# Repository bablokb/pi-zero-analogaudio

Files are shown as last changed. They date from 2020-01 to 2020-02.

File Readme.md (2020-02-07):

Pi-Zero-Analogaudio
===================

The Pi-Zero is a stripped down board, there is no analog audio jack
like on the bigger Pis. But it is no problem to add it using a few
simple and cheap components.

The schematic

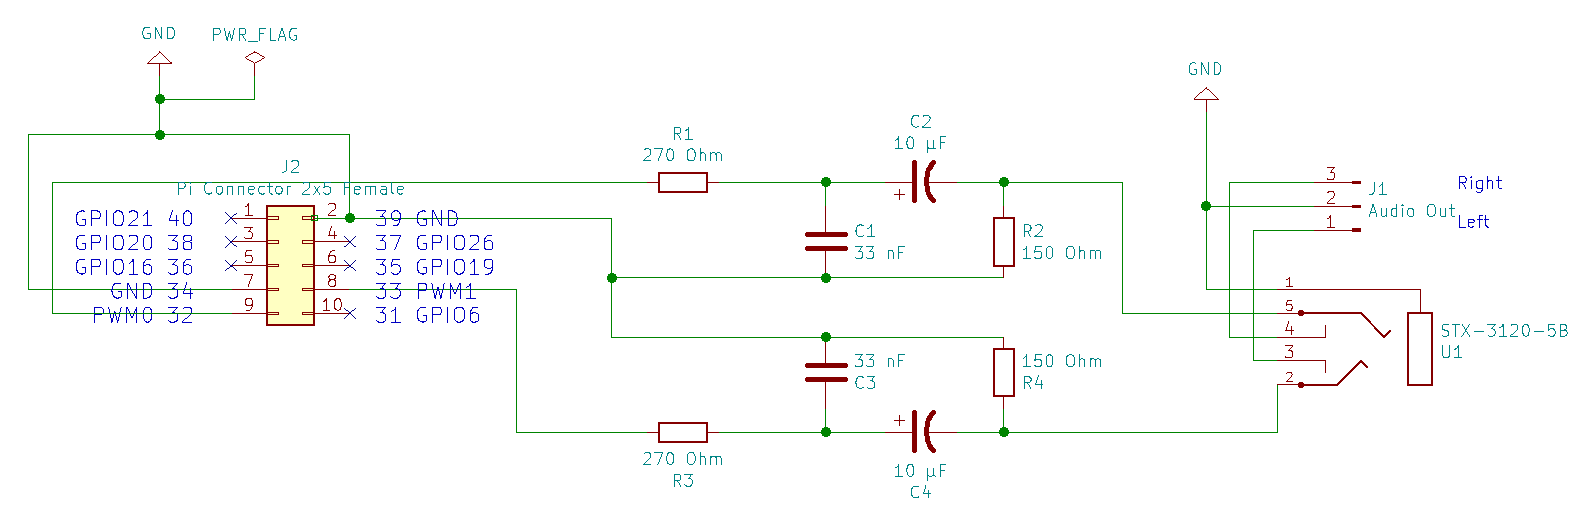
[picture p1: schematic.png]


shows the necessary parts and the wiring. Basically, you configure the
Zero to output pwm-signals, then you use a combination of a lowpass
and highpass filter to clean the signal on every channel.

The audio quality is ok, but not on hifi level. The filters limit the
frequency range and the signal is still not absolutely clean afterwards.
If you really need high-quality audio-output, use HDMI, bluetooth or
attach an audio-hat based on I2S using a DAC.

Hardware
========

Required parts:

  - two resistors 270 Ohm
  - two resistors 150 Ohm
  - two capacitors 33nF
  - two capacitors 10µF
  - an 3.5mm audio-jack (e.g. STX-3120-5B from Adafruit)
  - some jumper-wires

In the folder `kicad` you can find a complete pcb, designed for the above
throughhole components. You will need to adapt the design if you use a
different audio-jack.

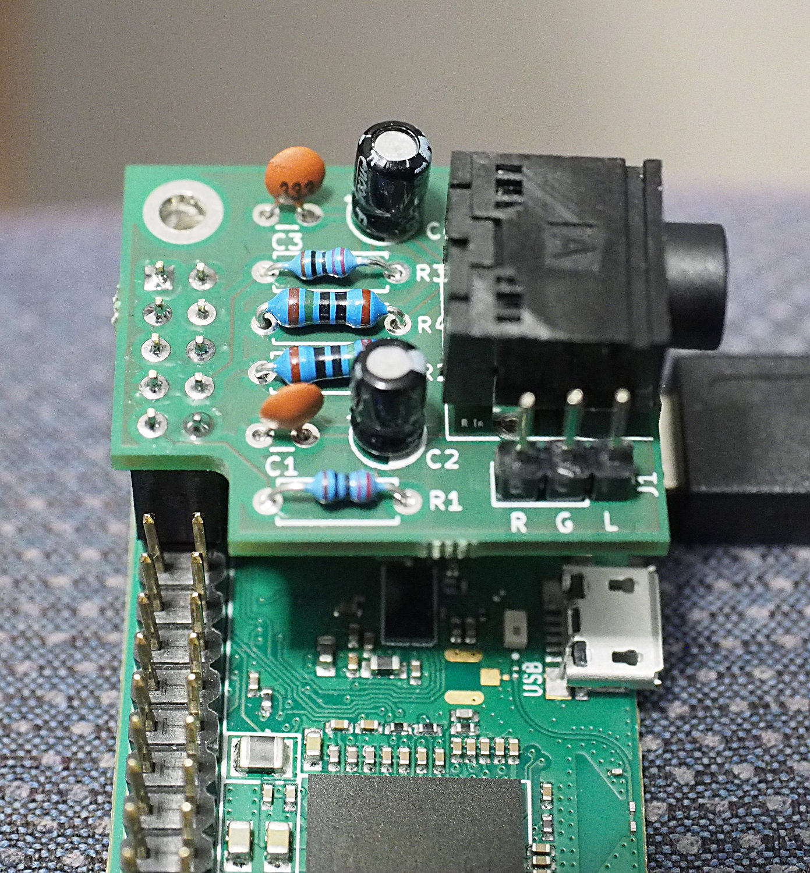
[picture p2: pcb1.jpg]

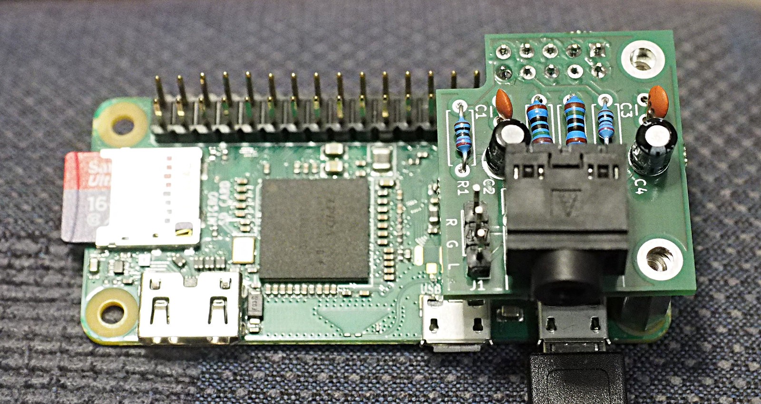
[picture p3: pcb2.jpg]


Software and System Configuration
=================================

You don't need special software, just use `aplay` to play wav-files or
e.g. `mpg123` for mp3-files.

You can configure the system manually, or you can clone the repository
and just run the install command:

    git clone https://github.com/bablokb/pi-zero-analogaudio.git
    cd pi-zero-analogaudio
    sudo tools/install

The install command will add the following lines to your `/boot/config.txt`:

    dtparam=audio=on
    dtoverlay=pwm-2chan,pin=12,func=4,pin2=13,func2=4

This configures analog-audio for the physical pins 32 and 33. Other
pin-combinations are possible, see the file `/boot/overlays/README` for
a complete list.

In addition, the install command runs

    amixer cset numid=3 1

This switches the audio-output from auto (0) or HDMI (2) to analog-out (1).
You can also use `raspi-config` for this task (or for switching back).

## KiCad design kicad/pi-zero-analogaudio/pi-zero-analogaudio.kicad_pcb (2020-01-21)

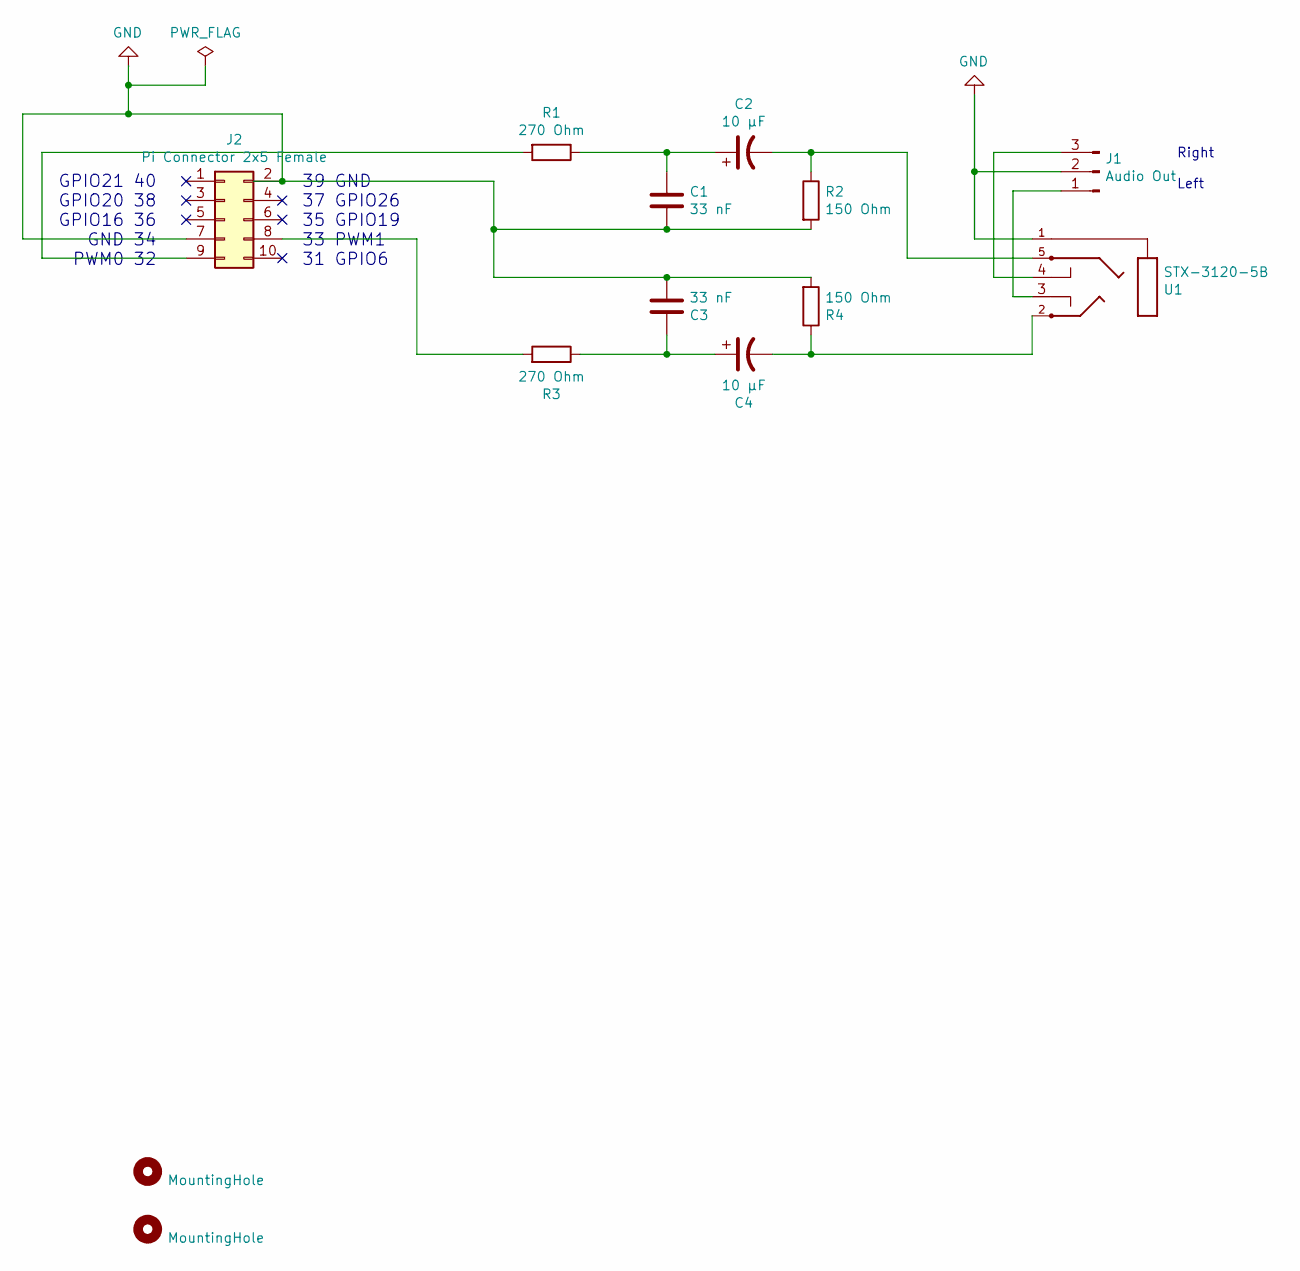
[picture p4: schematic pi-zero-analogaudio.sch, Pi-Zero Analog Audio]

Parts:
C1, C3: 33 nF; C_Disc_D3.0mm_W1.6mm_P2.50mm
C2, C4: 10 µF; CP_Radial_D4.0mm_P1.50mm
H1, H2: MountingHole; MountingHole_2.7mm_M2.5_DIN965_Pad
J1: Audio Out; PinHeader_1x03_P2.54mm_Vertical
J2: Pi Connector 2x5 Female; PinSocket_2x05_P2.54mm_Vertical
R1, R3: 270 Ohm; R_Axial_DIN0207_L6.3mm_D2.5mm_P7.62mm_Horizontal
R2, R4: 150 Ohm; R_Axial_DIN0207_L6.3mm_D2.5mm_P7.62mm_Horizontal
U1: STX-3120-5B

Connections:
GND: C1.2, C3.2, J1.2, J2.2, J2.7, R2.2, R4.2, U1.1
unnamed: C1.1, C2.1, R1.1
unnamed: C2.2, R2.1, U1.5
unnamed: C3.1, C4.1, R3.1
unnamed: C4.2, R4.1, U1.2
unnamed: J1.1, U1.3 (L_out)
unnamed: J1.3, U1.4 (R_out)
unnamed: J2.8, R3.2
unnamed: J2.9, R1.2

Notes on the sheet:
GPIO21 40 GPIO20 38 GPIO16 36 GND 34 PWM0 32
Right Left
39 GND 37 GPIO26 35 GPIO19 33 PWM1 31 GPIO6

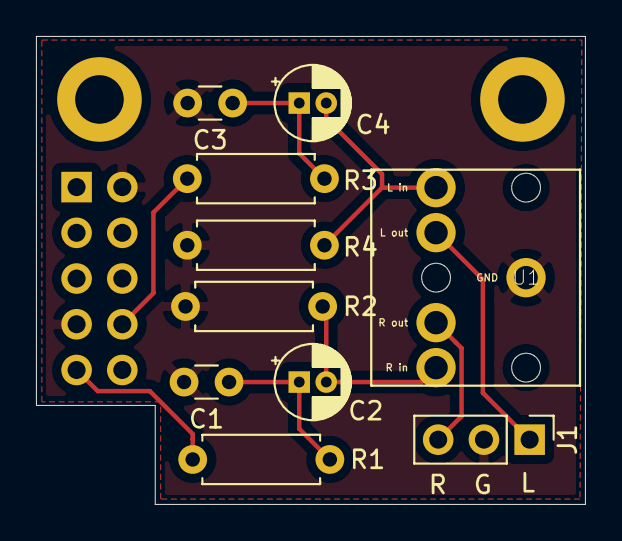
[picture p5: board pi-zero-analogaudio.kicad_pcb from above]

Board: 2 copper layers, 30.5 x 26.0 mm, 13 parts (1 on the bottom side), 9 nets.

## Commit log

2019-12-23 added 2x5 connector
    [pi-zero-analogaudio.sch]
2019-12-24 changed administrative metadata
    [pi-zero-analogaudio.sch]
2019-12-27 Revision 3: added connector for audio-out
    [pi-zero-analogaudio.sch]
2019-12-28 added footprints and started pcb
    [pi-zero-analogaudio.kicad_pcb, pi-zero-analogaudio.sch]
2019-12-29 fixed wrong connection for R4
    [pi-zero-analogaudio.kicad_pcb, pi-zero-analogaudio.sch]
2020-01-04 Revision 5: J3 with additional GND, connect pin34 with pin39
    [pi-zero-analogaudio.sch]
2020-01-04 updated pcb for revision 5
    [pi-zero-analogaudio.kicad_pcb]
2020-01-07 added GND/PWR_FLAG
    [pi-zero-analogaudio.sch]
2020-01-07 Revision 6: replace generic audio-jack with STX-3120-3B
    [pi-zero-analogaudio.sch]
2020-01-07 updated layout (size, components)
    [pi-zero-analogaudio.kicad_pcb, pi-zero-analogaudio.sch]
2020-01-08 slightly moved header to (hopefully) fit hat-dimensions
    [pi-zero-analogaudio.kicad_pcb]
2020-01-08 drilling holes, silk-screen print
    [pi-zero-analogaudio.kicad_pcb, pi-zero-analogaudio.sch]
2020-01-09 added copper-fill to F.Cu
    [pi-zero-analogaudio.kicad_pcb]
2020-01-09 Revision 7: mounting-hole with pad / small tweaks
    [pi-zero-analogaudio.kicad_pcb, pi-zero-analogaudio.sch]
2020-01-09 set labels H1/H2 to invisible
    [pi-zero-analogaudio.kicad_pcb, pi-zero-analogaudio.sch]
2020-01-12 Revision 8: replaced STX3120-3B with STX3120-5B
    [pi-zero-analogaudio.kicad_pcb, pi-zero-analogaudio.sch]
2020-01-18 updated to current version
2020-01-18 added cutoff
    [pi-zero-analogaudio.kicad_pcb]
2020-01-21 optimzed placement of labels
    [pi-zero-analogaudio.kicad_pcb]
2020-02-06 linked images of pcb
